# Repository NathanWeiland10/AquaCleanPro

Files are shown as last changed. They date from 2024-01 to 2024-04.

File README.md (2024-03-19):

<p align="center">
    <h1 align="center">Team AquaClean Pro</h1>
</p>

<p align="center">
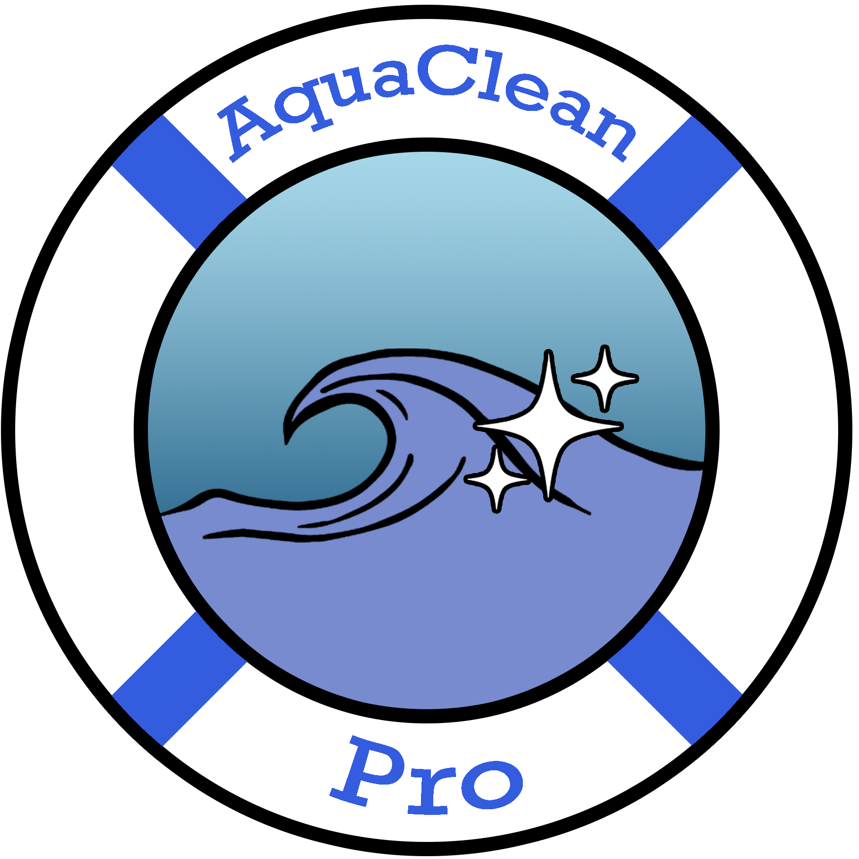
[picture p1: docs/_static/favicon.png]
    
</p>

## Overview
This repository is for Team Projects (CEG 4980 & 4981) from Fall 2023 to Spring 2024, Team #11 - AquaClean Pro. 

### Goal
To create a robot that can autonomously clean the surface of a residential pool and determine its quality. The robot will also have a user interface that will display the metrics of water quality. 

## Custom Domain
Our project uses a custom domain of `aquacleanpro.org` hosted through Squarespace domains. The services provided by under this custom domain can be found below.

1) ### Online Document Viewer
    * The AquaClean Pro Document Viewer (ACP-DV) can be found at [https://docs.aquacleanpro.org/](https://docs.aquacleanpro.org/), which contains information about source code, meeting minutes, and other supporting documentation:
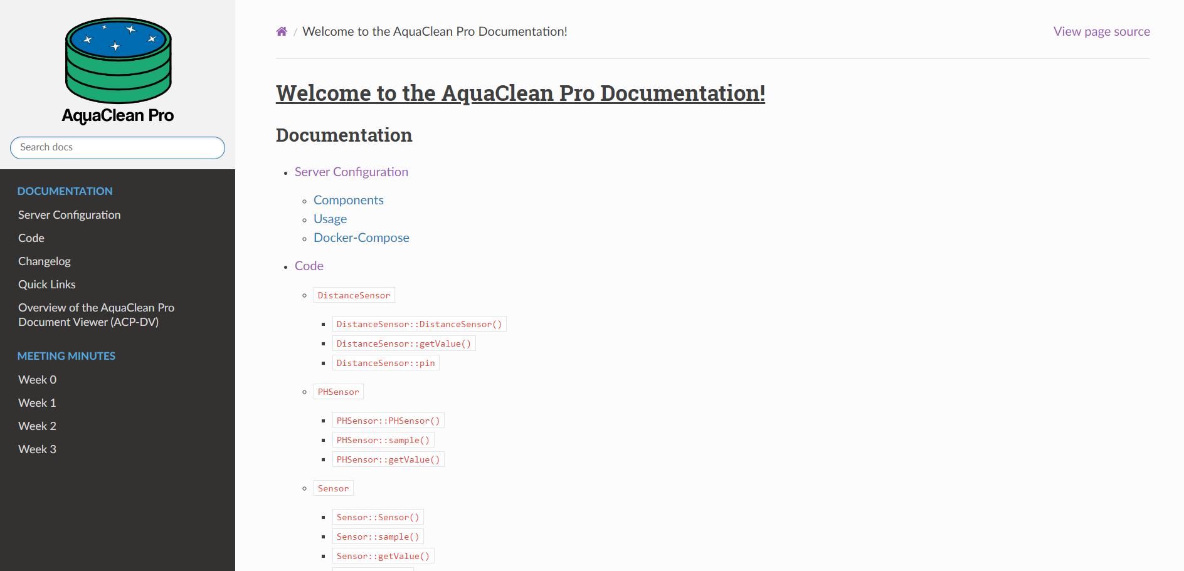
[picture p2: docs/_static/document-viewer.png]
    

2) ### Grafana (Frontend)
    * Our frontend using Grafana can be found at http://www.aquacleanpro.org:8000. Login credentials required.

3) ### pgAdmin (Backend)
    * Our admin portal for Postgres for our project can be found at http://www.aquacleanpro.org:4000/. Login credentials required.

4) ### PostgREST (Backend)
    * Our backend service using PostgREST for our project can be found at http://www.aquacleanpro.org:3000/.

### Model Design

<p align="center">
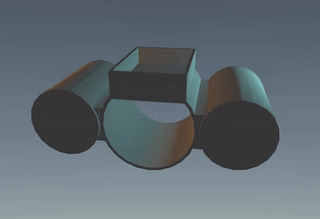
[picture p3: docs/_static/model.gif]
    
</p>

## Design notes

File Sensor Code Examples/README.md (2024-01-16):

## What is This Directory For?
This directory provides some code examples of the sensors that will be used by the Aqua Clean Pro as well as some documentation of where to find more information. A majority of these links have been scraped from links posted in an old Discord group chat.

## Quick References for Components
Below are the store pages for each of our components as well as some links to potentially useful web pages for each:
* ### [ESP32-WROOM-32E - Microprocessor / Microcontroller](https://www.digikey.com/en/products/detail/espressif-systems/ESP32-DEVKITC-32E/12091810)
    * [ESP32 Datasheet](https://www.espressif.com/sites/default/files/documentation/esp32_datasheet_en.pdf)
* ### [DS18B20 - Temperature Sensor](https://www.digikey.com/en/products/detail/adafruit-industries-llc/381/5875807)
* ### [SEN0161 - pH Sensor](https://www.dfrobot.com/product-1025.html)
* ### [Gravity: Analog Signal Isolator ](https://www.digikey.com/en/products/detail/dfrobot/DFR0504/7682221?s=N4IgTCBcDaICIDEBKAGArCgLCAugXyA)
* ### [A02YYUW - Waterproof Ultrasonic Distance Sensor ](https://www.dfrobot.com/product-1935.html)
* ### [Adafruit 3.7V Lithium-Ion Battery 4.4Ah](https://nam04.safelinks.protection.outlook.com/GetUrlReputation)
* ### [1738-1051-ND 2A Dual Motor Controller ](https://www.digikey.com/en/products/detail/dfrobot/DRI0002/6588473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)
* ### [M22E-13 - Propulsion / Steering Motor](https://www.digikey.com/en/products/detail/nmb-technologies-corporation/M22E-13/16677246)

## Other Helpful Links
Below are some links that could possible be useful for reference when coding or working with our electrical components:

## Arduino Specifics
* [Arduino Coding Guide](https://manual.eg.poly.edu/index.php/Arduino_Coding_Guide)
* [Arduino RC Boat Control Code Example](https://forum.arduino.cc/t/movement-of-rudder-on-rc-boat/679347/3)
* [Arduino Battery Level Checking Example](https://forum.arduino.cc/t/battery-level-check-using-arduino/424054/3)
* [Arduino Json](https://arduinojson.org/)

## Coding (C++)
* [C++ Bindings with Python Guide](https://www.blopig.com/blog/2021/03/c-python-bindings-in-5-minutes/)

## Encryption and Wireless Communication
* [802.11 Wi-Fi Standards Guide](https://www.lifewire.com/wireless-standards-802-11a-802-11b-g-n-and-802-11ac-816553)
* [AES (Advanced Encryption Standards) Guide](https://www.techtarget.com/searchsecurity/definition/Advanced-Encryption-Standard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,cybersecurity%20and%20electronic%20data%20protection)
* [AES Encryption Example Repo](https://github.com/kokke/tiny-AES-c)
* [TLS (Transport Layer Security) Guide](https://www.cloudflare.com/learning/ssl/transport-layer-security-tls/)
* [Initialize Wi-Fi Settings in a Production IOT Device](https://electronics.stackexchange.com/questions/495541/how-to-initialize-wifi-settings-in-a-production-iot-device)
* [WPA2 (Wireless Protected Access 2) Guide](https://www.avg.com/en/signal/what-is-wpa2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)

## Waterproofing
* [IP Waterproofing Standards](https://uk.rs-online.com/web/content/discovery/ideas-and-advice/ip-ratings)
* [Waterproof 3D Printing Guide](https://all3dp.com/2/waterproof-3d-print-pla/)

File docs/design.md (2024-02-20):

# Objectives 

**Goal**: To create a robot that can autonomously clean the surface of a residential pool and determine its quality. The robot will also have a user interface that will display the metrics of water quality. 

**Objective 1**: The robot can collect trash and debris on the surface of a body of freshwater. 
- Trash and debris refer to smaller pieces of waste that float on the surface of the water, such as wrappers, bottles, and aluminum cans, and would be unable to collect larger waste.  

**Objective 2**: The robot can take measurements of the water quality. 
- Water quality refers to four main statistics about the body of water the robot resides in: temperature, pH level, total dissolved solids, and turbidity. The robot periodically measures these numbers and transmits them wirelessly to be stored in a database.  

**Objective 3**: A wireless user interface can display metrics measured by the robot. 
- The User Interface could refer to a website that is hosted separately that displays the temperature, the pH level, turbidity, and total dissolved solids of the water; the four metrics the robot collects. 

**Objective 4**: The robot can autonomously move across the surface of the water. 
 - The robot moves across the surface of the water by use of propellors, avoiding collision by utilizing sensors to detect walls. 

# Assumptions 

| No. | Assumption |
|-----|---|
| 1 | The AquaClean Pro will only be operated in residential pools. |
| 2 | The AquaClean Pro will only pick up trash on the surface of the water. |
| 3 | Trash collected by the AquaClean Pro will be no larger than half the size of the attached pool skimmer. |
| 4 | User will provide power to sufficiently charge the AquaClean Pro. |
| 5 | User will provide an internet service for the AquaClean Pro. |
| 6 | The AquaClean Pro functions as a residential pool cleaning robot without an internet service provided by the user. |
| 7 | The AquaClean Pro will not operate in a body of water less than 2 feet deep. |
| 8 | User will not be inside of pool during cleaning. |
| 9 | User will empty the AquaClean Pro’s pool skimmer net when it’s full. |

# Requirements

| Req No. | Obj No. | Requirement |
| --- | --- | --- |
| 1.0 | 1, 4 | AquaClean Pro must collect buoyant solid waste on the surface of a residential pool. |
| 1.1 | 1, 4 | AquaClean Pro must haul at least 0.5 pounds. |
| 2.0 | 2 | AquaClean Pro must measure water quality. |
| 2.0.1 | 2 | The AquaClean Pro must store the water quality data. |
| 2.0.2 | 2, 3 | AquaClean Pro must transmit water quality data over a wireless internet connection at least once every 10 seconds when in operation. |
| 2.0.3 | 3 | AquaClean Pro must display water quality data to a web-accessible user interface. |
| 2.0.4 | 2 | AquaClean Pro shall collect accurate water quality data within an acceptable certainty range. |
| 3.0 | 4 | AquaClean Pro must identify surrounding walls. |
| 3.0.1 | 4 | AquaClean Pro must navigate surrounding walls during operation. |
| 4.0 | 4 | AquaClean Pro must float on the pool's surface. |
| 4.1 | 4 | The AquaClean Pro must reach a speed of at least 20cm/s in a forward direction relative to the device. |
| 4.2 | 4 | The AquaClean Pro must rotate about a fixed position. |
| 4.2.1 | 4 | The AquaClean Pro must have a full 360° rotation range in water along its vertical axis (Yaw). |
| 5.0 | 3 | AquaClean Pro’s battery level must be measured. |
| 5.0.1 | 3 | AquaClean Pro must transmit battery power level over a wireless internet connection at least once every 10 seconds when in operation. |
| 5.0.2 | 3 | AquaClean Pro must display battery power data to a web-accessible user interface. |
| 5.1 | 3, 4 | AquaClean Pro must alert the user once it reaches 20% remaining battery power or lower. |
| 6.0 | 4 | AquaClean Pro is water resistant to a depth of up to 2 feet. |
| 6.1 | 2 | AquaClean Pro’s water quality sensors’ probes must be waterproof. |
| 7.0 | 2, 3 | AquaClean Pro shall connect to a wireless network. |
| 7.0.1 | 2, 3 | The AquaClean Pro shall transmit data to a web-accessible user interface. |
| 7.1 | 2, 3 | The AquaClean Pro shall use end to end encryption for wireless communication. |
| 8.0 | 4 | The AquaClean Pro’s battery shall be charged from an external Micro USB power supply. |

## Definitions
**Buoyant solid waste** – Any objects that are on the surface of the residential pool, including but not limited to leaves, insects, and plastic wrappers. 

**Operation** – The robot’s state while skimming and cleaning the body of water. 

**Water quality data** – Temperature and pH measurements. 

**Acceptable certainty range** – Allowable uncertainty of sensors: 

- pH: ±0.1

- Temperature: ±1°C 

# Constraints 

| No. | Constraint |
| --- | --- |
| 1.0 | Total bill of materials shall not exceed $300 without Faculty Advisor approval. |
| 2.0 | The AquaClean Pro must fit within a box that has dimensions 45cm x 45cm x 60cm. |
| 3.0 | The AquaClean Pro weight must not exceed 20 kg before any trash is collected. |
| 4.0 | The AquaClean Pro’s speed shall not exceed 50cm/s. |
| 5.0 | The battery power shall not exceed 10Ah. |
| 6.0 | The AquaClean Pro wireless communication must adhere to one or more published IEEE standards. |
| 6.0.1 | The AquaClean Pro shall comply with IEEE 802.11 for wireless communication standards. |
| 7.0 | The AquaClean Pro must use end to end encryption for wireless communication. |
| 8.0 | Parts shall be sourced from WSU approved vendors: Digikey, Mouser, Robot Shop, MaxBotix, Midwest Surplus Electronics, or SparkFun. The list of approved vendors is subject to change. Updated lists of approved vendors will be posted in Pilot. |
| 9.0 | AquaClean Pro’s water quality and distance sensors’ probes must be waterproof to IP67 or higher. |

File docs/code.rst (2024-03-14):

====
Code
====

Main
----

.. doxygenfile:: source.ino

Base Sensor Class
-----------------

.. doxygenclass:: Sensor
    :members:

Temperature Sensor
------------------

.. doxygenclass:: TemperatureSensor
    :members:

pH Sensor
---------

.. doxygenclass:: PHSensor
    :members:

Distance Sensor
---------------

.. doxygenclass:: DistanceSensor
    :members:

Motor
-----

.. doxygenclass:: Motor
    :members:

Steering System
---------------

.. doxygenclass:: SteeringSystem
    :members:

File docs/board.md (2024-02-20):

# Development

For ESP-32 development, it is recommended to use the Arduino IDE ([download here](https://www.arduino.cc/en/software)). All required libraries and board interfaces can be installed through the IDE, however, the GitHub URLs are provided just in case.

## Required Libraries

The required libraries can be found by searching in the Arduino IDE's library manager (Tools > Manage Libraries).

- DS18B20 by Mathias Munk Hansen
    - https://github.com/matmunk/DS18B20
- WiFiManager by tzapu
    - https://github.com/tzapu/WiFiManager
- OneWire
    - https://www.pjrc.com/teensy/td_libs_OneWire.html
- HTTPClient by Adrian McEwan
    - https://github.com/amcewen/HttpClient

## Board Configuration

The board interface can be installed through the Arduino IDE's board manager (Tools > Board > Board Manager). The interface that works with our specific board was _DOIT ESP32 DEVKIT V1_ in the "[esp32 by Espressif Systems](https://github.com/espressif/arduino-esp32)" package.

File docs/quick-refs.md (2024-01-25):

# Quick Links

## What is this directory for?
This directory provides some code examples of the sensors that will be used by the Aqua Clean Pro as well as some documentation of where to find more information. A majority of these links have been scraped from links posted in an old Discord group chat.

## Quick References for Components
Below are the store pages for each of our components as well as some links to potentially useful web pages for each:
* ### [ESP32-WROOM-32E - Microprocessor / Microcontroller](https://www.digikey.com/en/products/detail/espressif-systems/ESP32-DEVKITC-32E/12091810)
    * [ESP32 Datasheet](https://www.espressif.com/sites/default/files/documentation/esp32_datasheet_en.pdf)
    * [ESP32 Emulator](https://wokwi.com/esp32)
* ### [DS18B20 - Temperature Sensor](https://www.digikey.com/en/products/detail/adafruit-industries-llc/381/5875807)
    * [Guide for Use With an Arduino #1](https://randomnerdtutorials.com/guide-for-ds18b20-temperature-sensor-with-arduino/)
    * [Guide for Use With an Arduino #2](https://lastminuteengineers.com/ds18b20-arduino-tutorial/)
    * [Guide for Use With an Arduino #3](https://www.instructables.com/How-to-use-DS18B20-Temperature-Sensor-Arduino-Tuto/)
* ### [SEN0161 - pH Sensor](https://www.dfrobot.com/product-1025.html)
    * [Guide for Use With an Arduino #1](https://wiki.dfrobot.com/PH_meter_SKU__SEN0161_)
    * [Guide for Use With an Arduino #2](https://wiki.dfrobot.com/Gravity__Analog_pH_Sensor_Meter_Kit_V2_SKU_SEN0161-V2)
    * [Guide for Use With an Arduino #3 (With GitHub Repo)](https://github.com/DFRobot/DFRobot_PH)
* ### [Gravity: Analog Signal Isolator](https://www.digikey.com/en/products/detail/dfrobot/DFR0504/7682221?s=N4IgTCBcDaICIDEBKAGArCgLCAugXyA)
    * [Component Guide](https://wiki.dfrobot.com/Gravity__Analog_Signal_Isolator_SKU_DFR0504)
* ### [A02YYUW - Waterproof Ultrasonic Distance Sensor](https://www.dfrobot.com/product-1935.html)
    * [Component Guide With Sample Code #1](https://wiki.dfrobot.com/_A02YYUW_Waterproof_Ultrasonic_Sensor_SKU_SEN0311)
    * [Component Guide With Sample Code #2](https://werner.rothschopf.net/microcontroller/202201_a02yyuw_ultrasonic_sensor_en.htm)
* ### [Adafruit 3.7V Lithium-Ion Battery 4.4Ah](https://nam04.safelinks.protection.outlook.com/GetUrlReputation)
* ### [1738-1051-ND 2A Dual Motor Controller](https://www.digikey.com/en/products/detail/dfrobot/DRI0002/6588473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)
    * [Component Guide](https://www.application-datasheet.com/pdf/dfrobot/508812/dri0002.html)
* ### [M22E-13 - Propulsion / Steering Motor](https://www.digikey.com/en/products/detail/nmb-technologies-corporation/M22E-13/16677246)

## Other Helpful Links
Below are some links that could possible be useful for reference when coding or working with our electrical components:

## Arduino Specifics
* [Arduino Coding Guide](https://manual.eg.poly.edu/index.php/Arduino_Coding_Guide)
* [Arduino RC Boat Control Code Example](https://forum.arduino.cc/t/movement-of-rudder-on-rc-boat/679347/3)
* [Arduino Battery Level Checking Example](https://forum.arduino.cc/t/battery-level-check-using-arduino/424054/3)
* [Arduino Json](https://arduinojson.org/)

## Coding (C++)
* [C++ Bindings with Python Guide](https://www.blopig.com/blog/2021/03/c-python-bindings-in-5-minutes/)
* [C++ Coding Guide](https://google.github.io/styleguide/cppguide.html)
* [JSF C++ Coding Standards](https://www.stroustrup.com/JSF-AV-rules.pdf)

## Encryption and Wireless Communication
* [802.11 Wi-Fi Standards Guide](https://www.lifewire.com/wireless-standards-802-11a-802-11b-g-n-and-802-11ac-816553)
* [AES 128 Overview](https://www.techtarget.com/searchsecurity/definition/Advanced-Encryption-Standard)
* [AES (Advanced Encryption Standards) Guide](https://www.techtarget.com/searchsecurity/definition/Advanced-Encryption-Standard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,cybersecurity%20and%20electronic%20data%20protection)
* [AES Encryption Example Repo](https://github.com/kokke/tiny-AES-c)
* [Initialize Wi-Fi Settings in a Production IOT Device](https://electronics.stackexchange.com/questions/495541/how-to-initialize-wifi-settings-in-a-production-iot-device)
* [TLS (Transport Layer Security) Guide](https://www.cloudflare.com/learning/ssl/transport-layer-security-tls/)
* [WPA2 (Wireless Protected Access 2) Guide](https://www.avg.com/en/signal/what-is-wpa2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)

## Waterproofing
* [IEC 60529 (IP Ratings)](https://webstore.iec.ch/preview/info_iec60529%7Bed2.1%7Db.pdf)
* [IP Ratings Overview](https://www.nbcnews.com/select/shopping/what-are-ip-ratings-rcna99835)
* [IP Waterproofing Standards](https://uk.rs-online.com/web/content/discovery/ideas-and-advice/ip-ratings)
* [Waterproof 3D Printing Guide](https://all3dp.com/2/waterproof-3d-print-pla/)

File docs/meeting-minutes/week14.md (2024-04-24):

# Week 14
## Thursday, April 18th, 2024
### Time
- 8:00am - 9:20am
### Attendees/Role
- Nathan
- Ethan T
- Ethan H
- Nermeen
- Thomas
### Decisions Made
- We did bug testing manually on each individual component to ensure they can run at the same time
- Nermeen, Nathan, Ethan T, and Thomas worked on rerouting the motors through the AQP and adding the propellers to them with the new adapters and the silicone sealant
- Ethan H. continues their work on the PostgREST decryption
- Nermeen has taken possession of the pool from Thomas (due to owning a hose)
- Thomas took a video of the motor code testing (before the actual test) for documentation purposes
### Questions or Concerns
- N/A

# Week 14
## Friday, April 19th, 2024
### Time
- 8:00am - 9:20am
### Attendees/Role
- Nathan
- Ethan T
- Ethan H
- Nermeen
- Thomas
### Decisions Made
- Ethan H. finished the decryption, and is now working on implementing encryption
- Thomas & Nathan worked to discover issue in Sensor library (Resolved by Ethan T.).
- Nathan edits videos Thomas took previously of AQP development for the final presentation
- Ethan T. brought in newly printed backplates for the ballasts with holes for rubber inserts (to control the water allowed in)
- Thomas, Nathan, & Nermeen sanded the new back plates to fit the ballasts
- Thomas, Nathan, Nermeen, & Ethan T. applied sealant to the new plates and got them in place
- Ethan T. completed integration of distance, temperature, and ph sensors into one script
### Questions or Concerns
- N/A

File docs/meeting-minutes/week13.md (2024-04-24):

# Week 13
## Thursday, April 11th, 2024
### Time
- 8:00am - 9:20am
### Attendees/Role
- Nathan
- Ethan T
- Ethan H
- Nermeen
- Thomas
### Decisions Made
- Ethan T sent an email to our Advisor (Buck) about presenting on Thursday April 25th at either 8:30am or 9:30am
- Ethan T and Nathan drilled hole in water-proof box to allow pH sensor wire to fit
- Nermeen ordered motor shaft adapters to attach our propellers
    - Issues could arise if we were to directly attach our propellers to the motor shaft since the adhesive could stick to the back of the motor
- Ethan T, Nathan, and Thomas applied more water-proof sealant to the edges of the craft
- Ethan H worked on PostgREST to fix our encrypted buffer table
- Clips were added to the front of the craft to hold our net in place
    - Net
### Questions or Concerns
- N/A

## Friday, April 12th, 2024
### Time
- 8:00am - 1:30pm
### Attendees/Role
- Nathan
- Ethan T
- Ethan H
- Nermeen
- Thomas
### Decisions Made
- Big work day:
    - Some tests for the battery were completed as well as tests for fitting together our components
    - Ethan H continued work on the postgREST side and posting to encryption buffer
    - Nathan, Nermeen, and Ethan T Found bits that we can glue the propellers / motor to and still turn
        - Nermeen will be taking home the motors / propellers to test other bits incase they work better
    - We tested the bot in a utility sink for leaks and waterproofness. It passed the buoyancy test but it failed the leak test.
    - Motor caps were sanded to fit on easier 
- Next steps:
    - Fix issues with integrating our code for our sensors together
    - Complete remaining tests and add results to our complete design document
    - Finish slides for presentation and assign slider numbers
### Questions or Concerns
- N/A

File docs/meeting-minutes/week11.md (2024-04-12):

# Week 11
## Thursday, March 28th, 2024
### Time
- 8:00am - 9:20am
### Attendees/Role
- Nathan
- Ethan T
- Nermeen
- Thomas
### Decisions Made
- Nermeen began work on wiring all of our electrical components together
- Ethan T finished and brought in the full 3D printed model
- Nathan and Thomas began sealing the cracks on the outside of the 3D model pieces to ensure that the design is waterproof
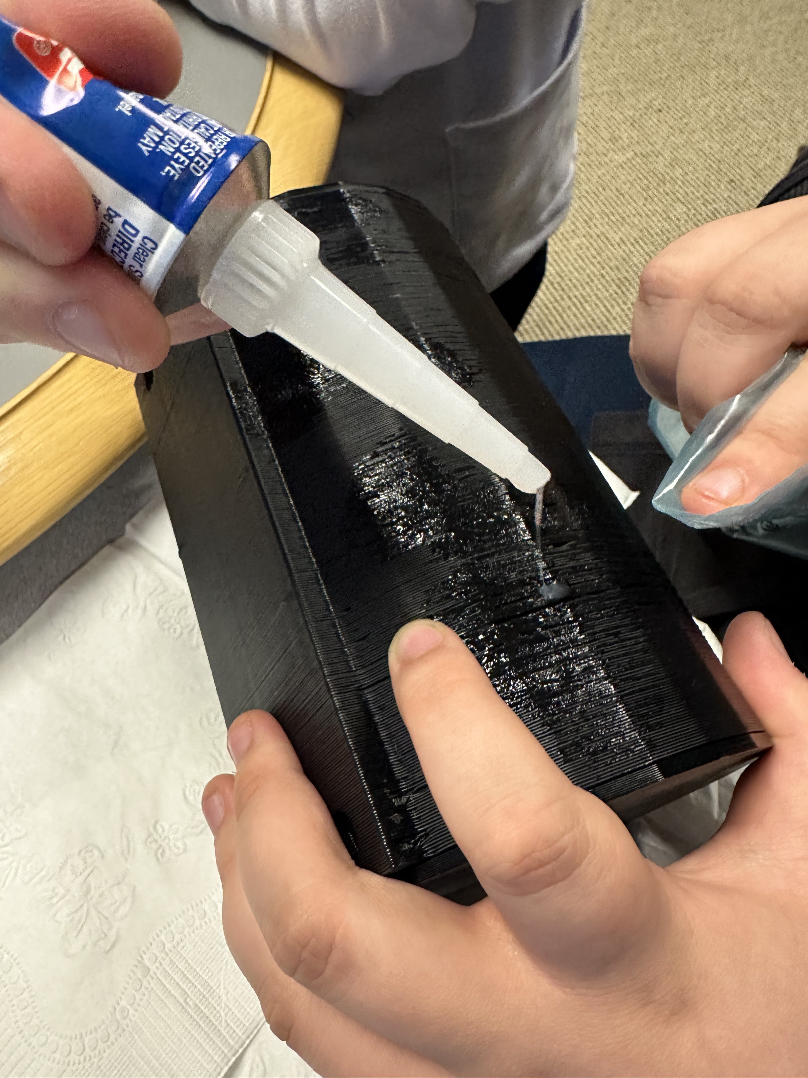
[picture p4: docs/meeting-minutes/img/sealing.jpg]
Sealing
    - 
### Questions or Concerns
- Still waiting for a response from Billy Willis about using the WSU swimming pool for running our tests
    - Possible backup: Buy a small swimming pool from Meijer to test in

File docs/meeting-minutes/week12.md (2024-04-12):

# Week 12
## Tuesday, April 2nd, 2024
### Time
- 8:00am - 9:20am
### Attendees/Role
- Nathan
- Ethan T
- Ethan H
- Nermeen
- Thomas
### Decisions Made
- Ethan T began sanding down the design to ensure a better fit among the different pieces.
- Ethan T, Nermeen, and Nathan also started constructing the whole craft by putting together all the sealed pieces.
- Thomas, Nathan, and Ethan T started sealing up the holes in the craft with the sealant and stuck the various parts of the print together to make the final craft.
- Nermeen and Nathan started assembling the electrical components in the waterproof box to get wires through.
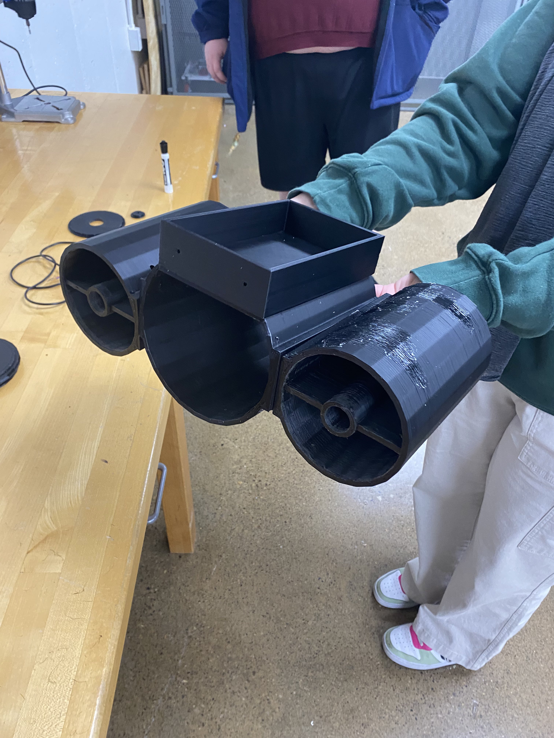
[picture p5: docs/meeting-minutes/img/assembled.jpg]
Together
    - 
- Ethan H is running into issues with the decryption pipeline, currently attempting some fixes to locate where the issue is and fix it before testing next week.
### Questions or Concerns
- From discussing with another group, renting the pool for testing can cost up to $20 an hour
    - To do this, we will also need to fill out a form, which can be found [here](https://www.wright.edu/sites/www.wright.edu/files/page/attachments/facility-request-form_0.pdf)

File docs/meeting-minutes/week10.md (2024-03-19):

# Week 10
## Tuesday, March 19th, 2024
### Time
- 8:00am - 9:20am
### Attendees/Role
- Nathan
- Ethan T
- Ethan H
- Nermeen
- Thomas
### Decisions Made
- We created new propellers due to issues with the propellers we purchased:
    - The propellers we have do not fit well onto our motor bit
    - Issues might arise if we need to glue the propeller shaft to the motor bit, so we would need an extension of the motor shaft
- Our new propeller design addresses both of these issues and we have the ability to adjust the model as needed due to excess filament
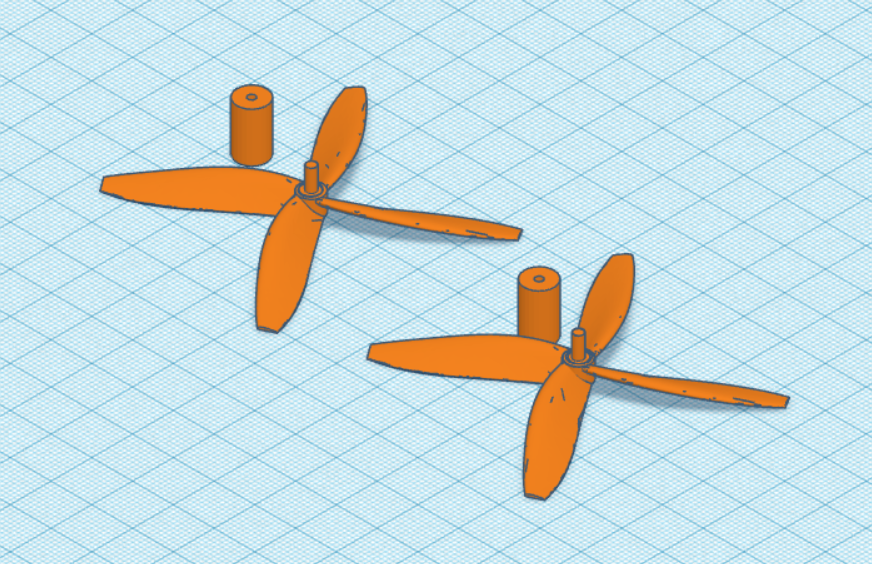
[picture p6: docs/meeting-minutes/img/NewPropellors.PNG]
Propellers
    - 
- Ethan T printed the first segment for the AquaClean Pro
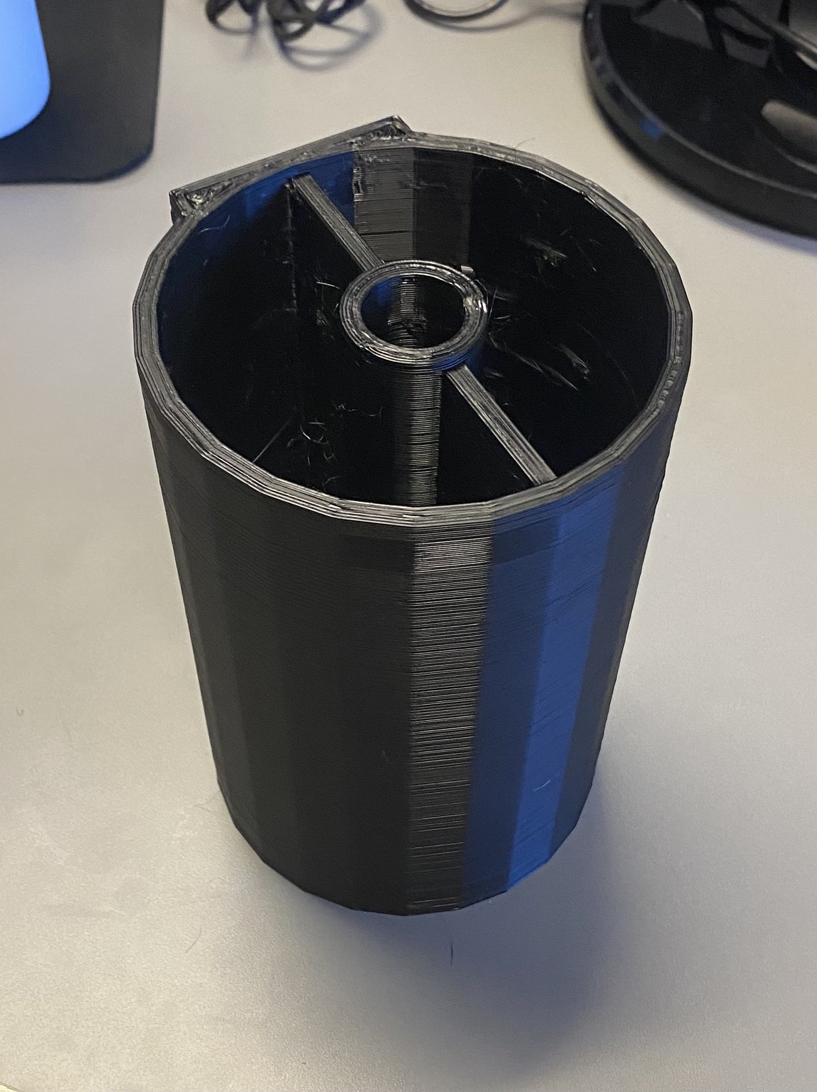
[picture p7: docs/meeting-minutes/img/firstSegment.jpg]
First_Segment
    - 
- Ethan T calibrated the pH sensor to get the correct values for the pH offset (526.035) and curve (143.133)
### Questions or Concerns
- N/A

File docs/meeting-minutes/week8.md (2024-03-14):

# Week 8
## Thursday, March 7th, 2024
### Time
- 8:30am - 9:20am
### Attendees/Role
- Nathan
- Ethan T
- Ethan H
- Nermeen
- Thomas
### Decisions Made
- Ethan T and Nermeen worked on distance sensor and motor code and tested on an ESP-32
- Nathan, Ethan H, and Thomas worked on testing encryption code on an ESP-32
    - The code worked, however, the encrypted data will need to be converted into JSON format and a new table will need to be created in PostgREST
- Nathan and Ethan T went to Russ basement to test motor and motor drivers on ESP-32 with voltages of 3.7 and 6.5. Both cases were successful
### Questions or Concerns
- Our battery is 3.7V, however, a design sheet specifies that we need 6.5V for our motor driver.
    - From testing, we found that the motor driver still works with only 3.7V, but a new battery can be purchased if necessary
- Our motors are not waterproof
    - We have the budget to buy new motors, or we can use our waterproof sealant to waterproof the motors

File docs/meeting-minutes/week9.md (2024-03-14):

# Week 9
## Thursday, March 14th, 2024
### Time
- 8:30am - 9:20am
### Attendees/Role
- Nathan
- Ethan T
- Ethan H
- Nermeen
- Thomas
### Decisions Made
- We tested our pH sensor and was able to correctly read in values. A calibration testing kit has purchased by Ethan T so that we can ensure the values read in are correct
- We decided to update the 3D model for the AquaClean Pro. Tinkercad was used for the software since it was simpler to use and allowed us all to view and make changes to the model at the same time. The new model also addresses some of the issues we found with the previous model, such as the buoyancy and balance of the model, pathing of the wires from the water-proof box to the motors, and potential issues when printing the model (such as needing supports)
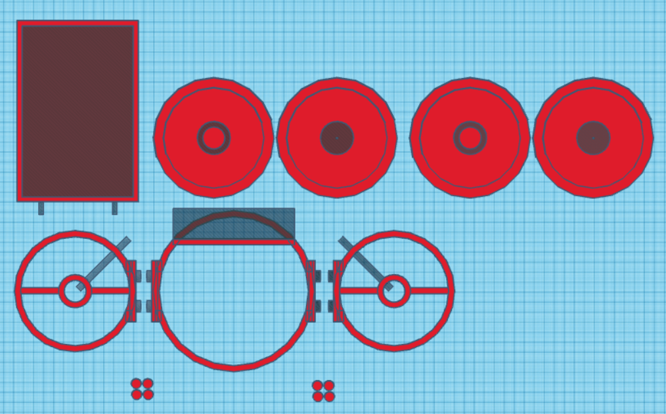
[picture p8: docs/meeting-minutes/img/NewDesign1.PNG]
    - 
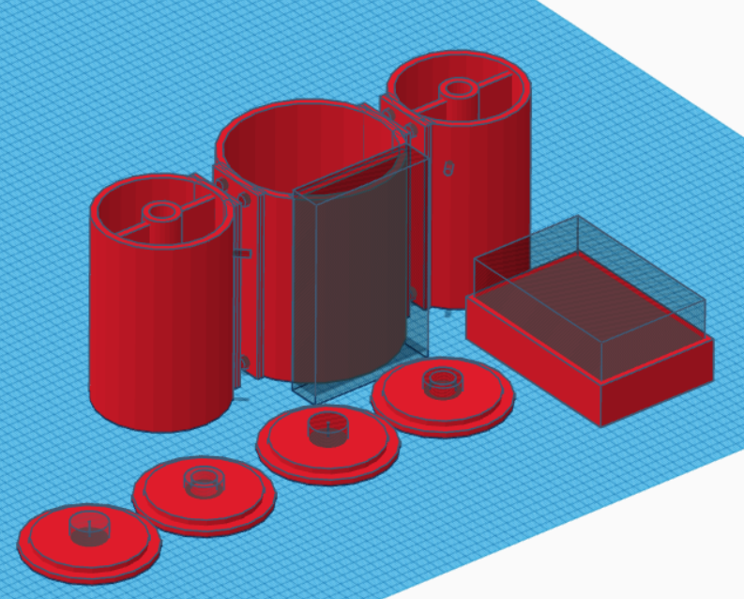
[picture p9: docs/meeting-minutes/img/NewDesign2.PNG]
    - 
- We are hoping to have the 3D model completed and printed by next week so that we can begin integrating our components
### Questions or Concerns
- N/A

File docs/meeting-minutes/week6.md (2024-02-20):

# Week 6
## Tuesday, February 20, 2024
### Time
- 9:00am - 9:20am
### Attendees/Role
- Nathan
- Ethan T
- Ethan H
- Nermeen
- Thomas
### Decisions Made
- Ethan H worked on demoes for encryptions on Arduino and PostgREST in C
- Ethan T added to the online document viewer a development tab for configuring code in the Arduino IDE
- A majority of team member installed the Arduino IDE and tested to make sure code could be compiled
    - The WiFi setup code written by Ethan T was tested
- Over spring break, we won't assign any new action items, however, team members can pick up work if they would like to
### Questions or Concerns
- N/A

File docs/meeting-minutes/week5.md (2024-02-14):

# Week 5
## Tuesday, February 13, 2024
### Time
- 8:30am - 9:20am
### Attendees/Role
- Nathan
- Ethan T
- Ethan H
- Nermeen
- Thomas
### Decisions Made
- Movement controls using the distance sensor; two possible options
    - 1: Start the bot in a corner and have it move straight until it reaches the next corner. Rotate the bot 90 degrees, move forward a small amount, rotate another 90 degrees, then move forward until it reaches a wall. Continue this until the bot reaches a corner. This could potentially still work if the bot is not placed directly in the corner
        - 
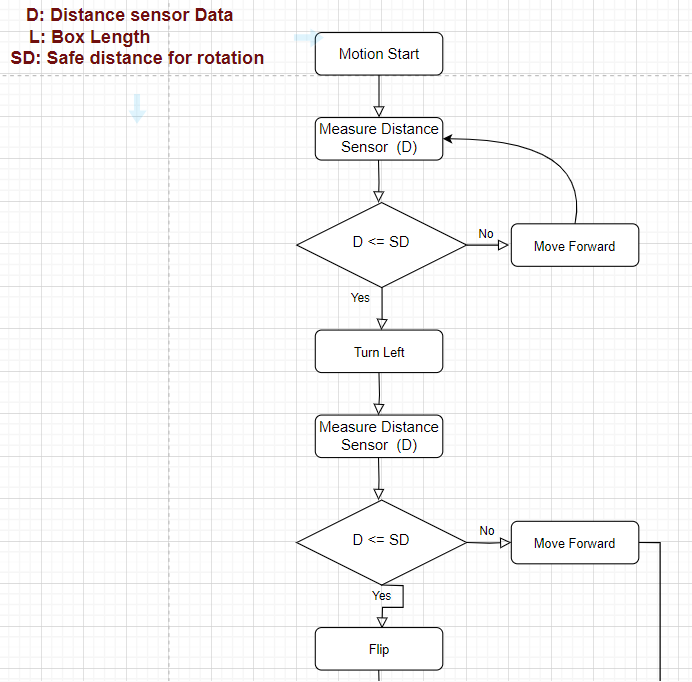
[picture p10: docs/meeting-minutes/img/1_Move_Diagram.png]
        - 
        - 
    - 2: Have the bot move forward from anywhere starting in the pool. Once the bot reaches a wall, have the bot rotate until it no longer is within a certain range of the wall, rotate a certain number of additional degrees (value can be tweaked later), and move forward. Continue this process.
        - 
    - Both designs
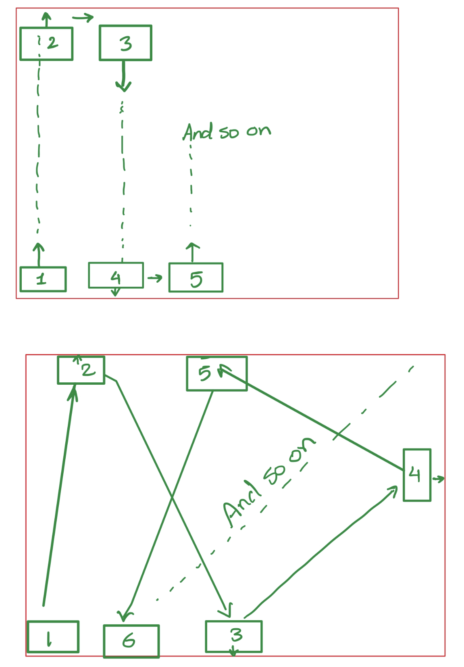
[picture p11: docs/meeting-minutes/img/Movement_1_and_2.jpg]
    - 
 - <b>Action Items:</b>
    - Nermeen: Distance sensor coding (using personal ESP)
    - Ethan T: pH sensor coding (using personal ESP)
    - Ethan H: Focusing on PostgREST
    - Nathan: Motor coding (using Tinkercad with an Arduino)
    - Thomas: Temperature sensor coding (using Wokwi emulator - DS18B20)
### Questions or Concerns
- Drilling holes into the waterproof box to allow the wiring to go through
    - We will manually drill holes into the box rather than using the sealing nuts so it will fit the design we have created. The only external wiring would be for the two motors and the distance sensor. We can waterproof by using the sealant we have.
- The motors we got did not come with wires, but we have ones we can use.

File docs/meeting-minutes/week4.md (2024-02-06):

# Week 4
## Tuesday, February 6, 2024
### Time
- 8:30am - 9:20am
### Attendees/Role
- Nathan
- Ethan T
- Ethan H
- Nermeen
- Thomas
### Decisions Made
- Update the 3D model:
    - Removing a section of the back wall and replacing it with L-shaped channels for wiring (removing the blue square area). This will allow for extra room for netting and to reduce drag in the water.
    - Adding counterweight for motors by filling in the front portions of the ballasts of where our motors will be (the red circles).
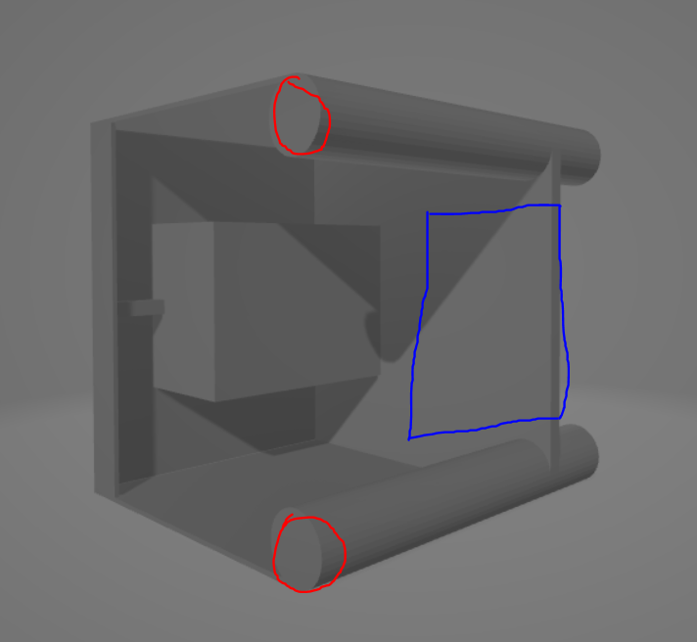
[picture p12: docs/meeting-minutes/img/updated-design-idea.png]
    
- Possibility of adding cosmetics or decorations after printing as time allows.
- Meeting at Joshi 367 on Tuesdays, and meeting on Thursdays at Joshi 367 if needed. Tuesday was chosen over Thursday because it is earlier in the week, providing us with more time to work.
### Questions or Concerns
- Talk to Billy about finding where our parts are. We checked the basement of Russ and they were not there.

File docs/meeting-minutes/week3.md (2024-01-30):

# Week 3
## Tuesday, January 30, 2024
### Time
- 8:00am - 9:20am
### Attendees/Role
- Nathan
- Ethan T
- Ethan H
- Nermeen
- Thomas
### Decisions Made
- Propellors will be difficult to 3D print. Instead, we will order them from Amazon. The following link was chosen due to their shaft width (3mm) and diameter (32mm) to fit the existing enclosure design. Nermeen has emailed Billy to add it to our order. (https://www.amazon.com/dp/B07RHK1TFS/ref=sspa_dk_detail_9)
- The pH sensor we ordered was on backorder until March 8th. We've found the following alternative available on Amazon which will hopefully arrive before March 8th and emailed Lynn Rhea asking to replace the item. (https://www.amazon.com/Accuracy-Connect-Terminal-Electrode-Detection/dp/B08GYF269Y)
- **Action Items:**
    - Ethan H will figure out the decryption between PostgreSQL/PostgREST and Grafana. Executing the TinyAES decryption function inside PostgreSQL may be a solution.
    - Nathan will update the documentation on how to update the documentation.
    - Thomas will try to emulate a pH sensor with WOKWI.
    - Ethan T will start trying to print the enclosure.
### Questions or Concerns
- Buck let us know that we're allowed to meet only once a week and it doesn't have to be during our scheduled class time or in SSC. Do we want to start meeting one day a week? Do we want to meet in Russ? If we want to meet during a time outside of our scheduled class, Buck has to be available.

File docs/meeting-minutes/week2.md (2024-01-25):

# Week 2
## Thursday, January 25th, 2024
### Time
- 8:30am - 9:00pm
### Attendees/Role
- Nathan
- Ethan T
- Ethan H
- Nermeen
- Thomas
### Decisions Made
- Using pre-made propellers instead of printing them
    - Adjust the width of the propeller ports from 40mm to 45mm
    - Nathan will send an email to Buck and Billy to include the pre-made propeller in our budget / list of materials
- Since our parts still have not arrived, we can use some of our own equipment for testing, such as testing with an ESP-32, or use online emulators.
- Ensure that Grafana is connected with the backend for sending data
- **Action Items:**
    - Ethan H will work on the Grafana display
    - Ethan T will work on connectivity of the ESP-32
    - Nathan will work on the issues with GitHub pages and finish the documentation for the docs viewer
    - Nermeen will focus on the 3D printing / motor housing and setup Tinkercad accounts
    - Thomas will focus on using Tinkercad / Wowki for writing code for the ESP-32
### Questions or Concerns
- Concern: Check in to see the status of our parts - especially for 3D printing
- Issue with GitHub pages resetting our custom domain of "docs.aquacleanpro.org" - we may need to configure the settings in Squarespace

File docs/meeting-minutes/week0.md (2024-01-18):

# Week 0
## Tuesday, January 9th, 2024
### Time
- 9:00am - 9:20am
### Attendees/Role
- Nathan
- Ethan T
- Ethan H
- Nermeen
### Decisions Made
- Hollowing the 3D printed design; walls will be less than 5cm
### Questions or Concerns
- How / where to host our server?
- AquaClean Pro Design:
    - How to design in a way that we can wire the motors?

## Thursday, January 11th, 2024
### Time
- 8:45am - 9:20am
### Attendees/Role
- Nathan
- Ethan T
- Ethan H
- Nermeen
- Thomas
### Decisions Made
- Thomas will create folder in the Sharepoint and template for final report as well as create template for presentation
- Ethan H will focus on setting up PostgreSQL
- Ethan T will focus on setting up the server to host the AquaCleanPro and created a Discord server for communication
- Nermmen will submit the bill of materials again and focus on the 3D model of the AquaCleanPro
    - Issue: What size should the hatch be to hold the water proof box?
        - Possible solution: Design the hatch slightly larger than the box (+10mm for each dimension) and use clear epoxy to fill in the space
- Nathan will create a folder in this GitHub repo with samples and documentation of sensor code for use with the Arduino
### Questions or Concerns
- Determine the status of our bill of materials
- After a few weeks, discuss with our advisor the possibility of meeting at a separatime time and location

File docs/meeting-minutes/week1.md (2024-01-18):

# Week 1
## Thursday, January 18th, 2024
### Time
- 9:00am - 9:20am
### Attendees/Role
- Nathan
- Ethan T
- Ethan H
- Nermeen
### Decisions Made
- Switching to a more catamaran-esque design for the bot to help with buoyancy/balance.
### Questions or Concerns
- How large should the device be?
    - Must fit on the print bed
    - Must be less than 3kg total
    - Must be large enough to fit our components

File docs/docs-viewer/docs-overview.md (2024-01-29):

# Overview of the AquaClean Pro Document Viewer (ACP-DV)
* The ACP-DV can be found at [https://nathanweiland10.github.io/AquaCleanPro/](https://nathanweiland10.github.io/AquaCleanPro/) or under the custom domain [https://docs.aquacleanpro.org/](https://docs.aquacleanpro.org/).
* The ACP-DV contains source code for the AquaClean Pro, meeting minutes, and other useful links and resources regarding the development and use of the AquaClean Pro.

## Adding Files to the ACP-DV
* To add files to the ACP-DV, follow these steps:
    1) Create a new GitHub branch from the repo: [https://github.com/NathanWeiland10/AquaCleanPro](https://github.com/NathanWeiland10/AquaCleanPro) and create a markdown file. Typically these files should be placed in the `docs` directory.
    2) Under the `docs` directory, locate the `index.rst` file. The file should look like the following:
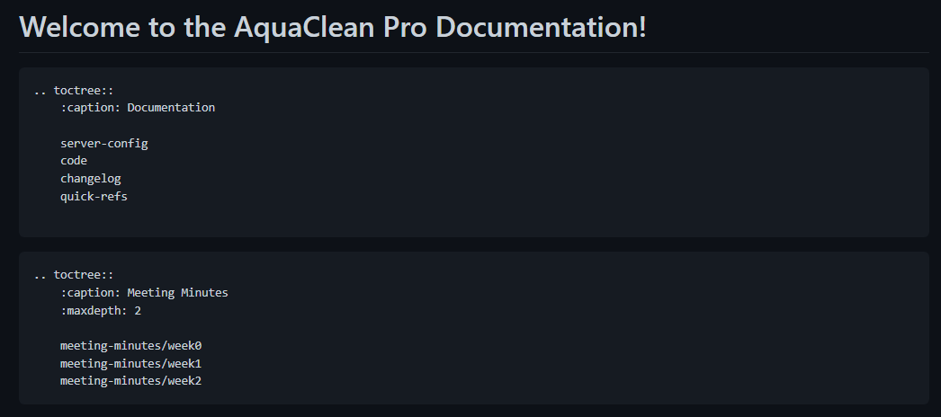
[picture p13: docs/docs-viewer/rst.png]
index.rst File
        * 
    3) Either add to an existing `.. toctree::` or create a new one. Creating a new `.. toctree::` with a specified caption will create a header in the ACP-DV, as shown in the following for "Documentation":
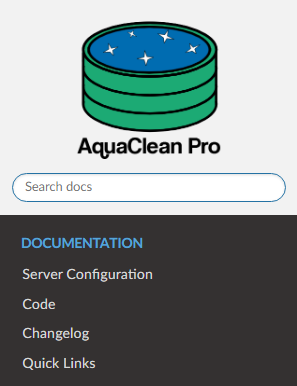
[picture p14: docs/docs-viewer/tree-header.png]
Tree Header
        * 
    4) Add the relative path of the markdown file under the `.. toctree::`.
    5) Upload your branch / push your changes to the [GitHub repo](https://github.com/NathanWeiland10/AquaCleanPro). An automated job should be ran which will allow you to view the ACP-DV before it goes live at https://docs.aquacleanpro.org/. This can be found by clicking on the `Actions` tab, then the changes you pushed. Near the bottom you will find the local version of the ACP-DV. Extract the file and open `index.html`:
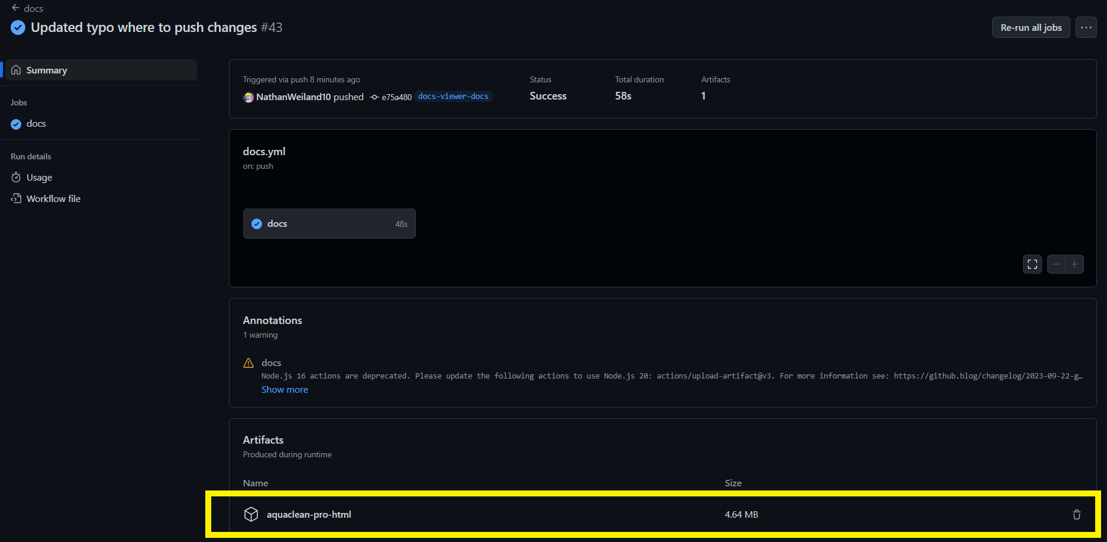
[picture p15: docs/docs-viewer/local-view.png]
Local View
        * 
    6) Push your changes to the `main` branch after you have viewed the local version of the ACP-DV and are satisfied with the changes. An automated script will be ran to add your changes to the live ACP-DV, which can be found at https://docs.aquacleanpro.org/.

## Notes About Markdown Files in the ACP-DV
* Header levels matter in your markdown files regarding the ACP-DV. A header level of one (i.e., a single hashtag `#`) will act as a header for the name of the file. For example, in the below example, the level one header of the file will be displayed in the viewer (Ex: "Server Configuration"), **not the name of the file itself**:
    * Tree Header

## Current Issues with the ACP-DV
* When changes are pushed to the `gh-pages` branch, the custom domain of `docs.aquacleanpro.org` is reset and manually needs to be updated in the [GitHub repo](https://github.com/NathanWeiland10/AquaCleanPro) under Setting -> Pages -> Custom domain:
    * Custom Domain

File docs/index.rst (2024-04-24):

###########################################
Welcome to the AquaClean Pro Documentation!
###########################################

.. toctree::
    :caption: Design

    design
    
.. toctree::
    :caption: Documentation

    server-config
    board
    code 
    changelog
    quick-refs
    docs-viewer/docs-overview

.. toctree::
    :caption: Meeting Minutes
    :maxdepth: 2

    meeting-minutes/week0
    meeting-minutes/week1
    meeting-minutes/week2
    meeting-minutes/week3
    meeting-minutes/week4
    meeting-minutes/week5
    meeting-minutes/week6
    meeting-minutes/week8
    meeting-minutes/week9
    meeting-minutes/week10
    meeting-minutes/week11
    meeting-minutes/week12
    meeting-minutes/week13
    meeting-minutes/week14

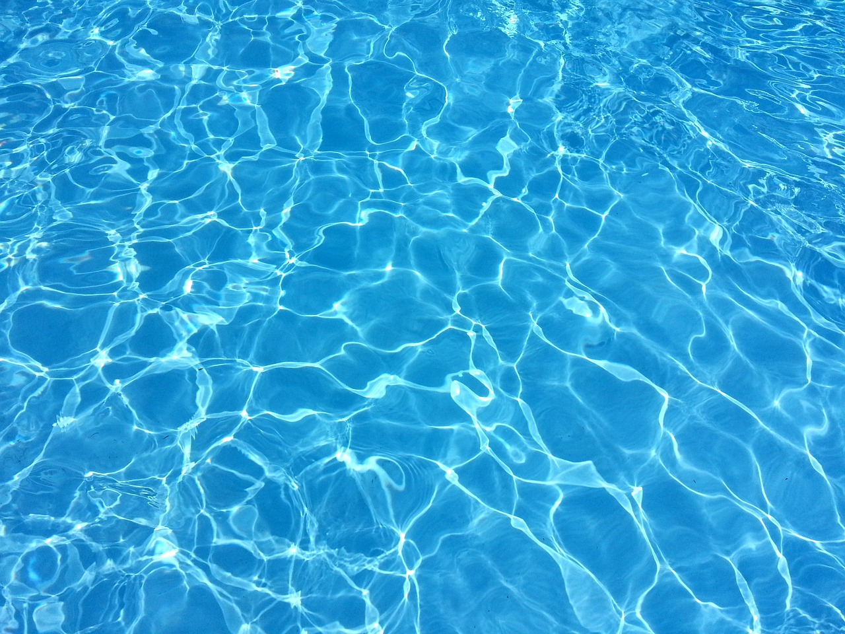
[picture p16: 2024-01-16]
docs/_static/pool.jpg

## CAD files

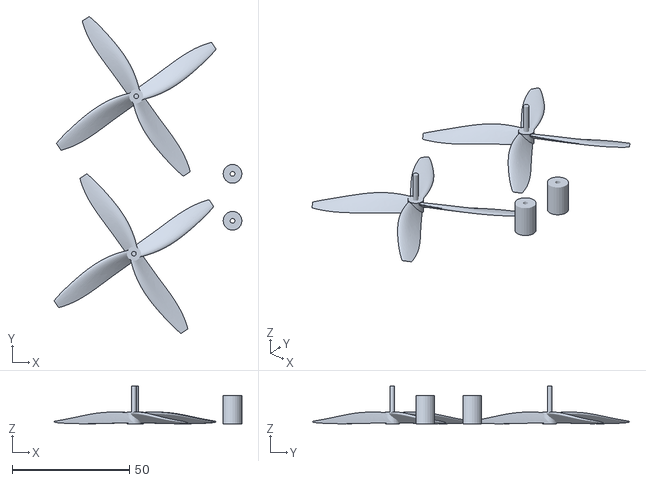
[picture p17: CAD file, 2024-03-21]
models/propellors.stl
80.0 x 135.0 x 16.0

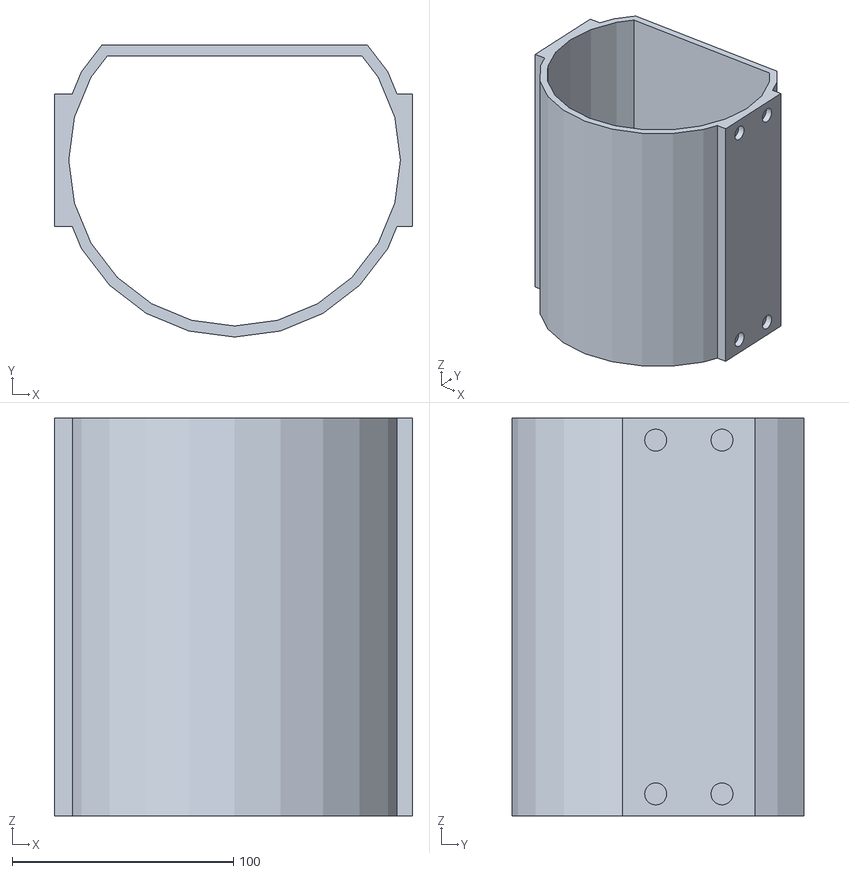
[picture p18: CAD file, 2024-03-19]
models/middle-collector.stl
162.0 x 132.1 x 180.0

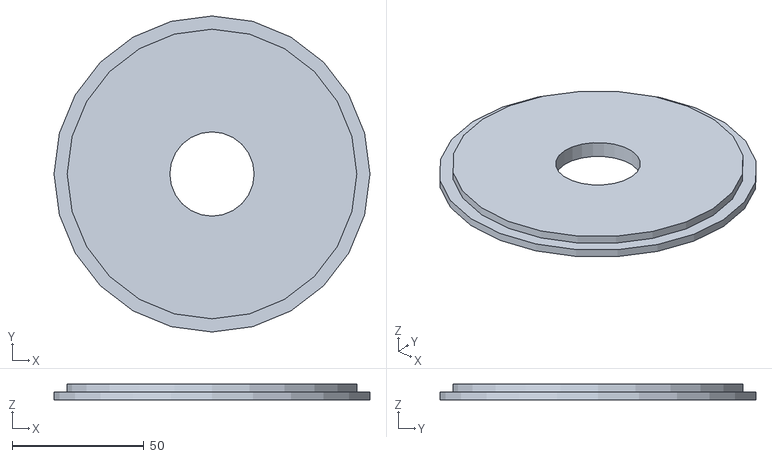
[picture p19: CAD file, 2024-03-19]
models/big-cap-with-hole.stl
120.0 x 120.0 x 6.00

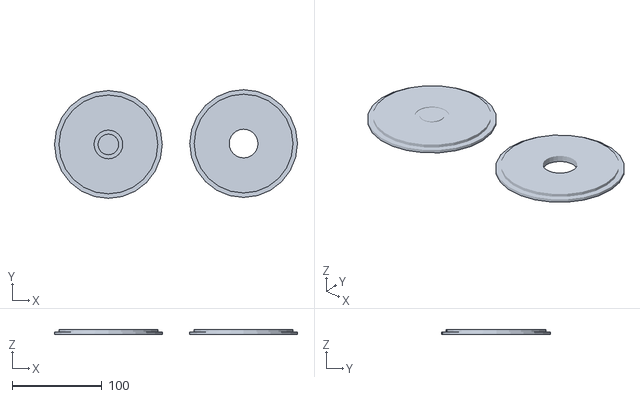
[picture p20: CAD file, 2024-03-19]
models/big-caps.stl
270.5 x 121.0 x 6.00

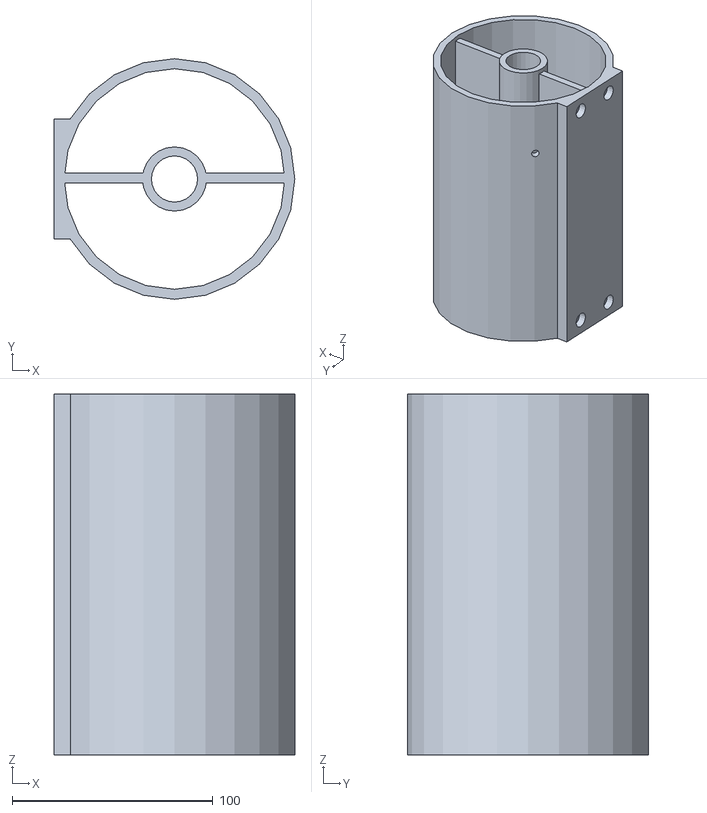
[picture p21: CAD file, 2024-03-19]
models/right-ballast.stl
120.0 x 120.0 x 180.0

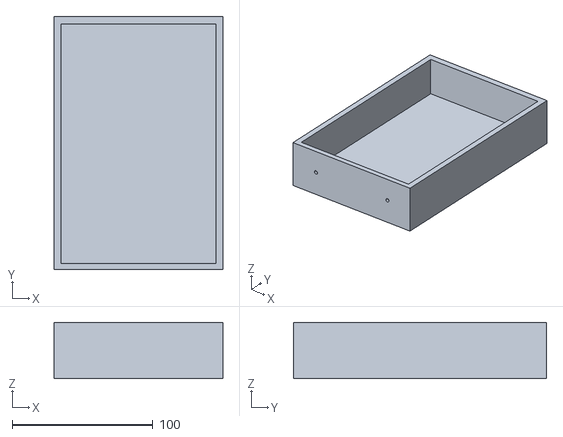
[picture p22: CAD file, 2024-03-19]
models/top-box.stl
120.0 x 180.0 x 40.0

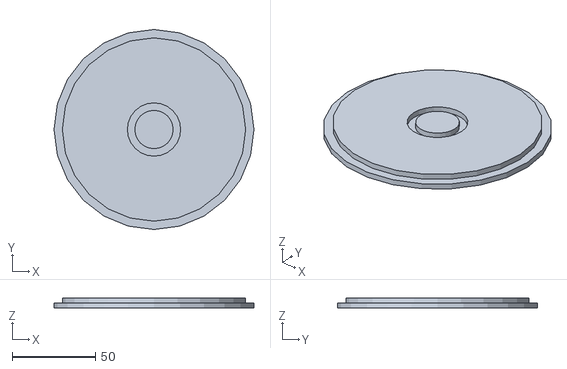
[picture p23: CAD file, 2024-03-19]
models/big-cap-no-hole.stl
120.0 x 120.0 x 6.00

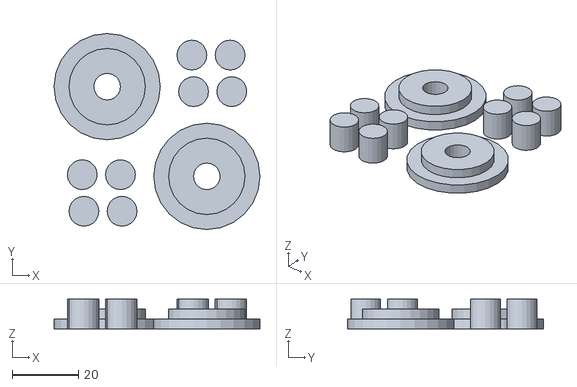
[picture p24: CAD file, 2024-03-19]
models/caps-and-pegs.stl
62.0 x 59.0 x 9.00

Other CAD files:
models/left-ballast.stl

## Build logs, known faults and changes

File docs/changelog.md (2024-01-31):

# Changelog

## Week 3
- Added WiFi portal and HTTP POST functionality. Currently uploads dummy data.

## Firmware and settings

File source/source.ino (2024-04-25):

#include "Arduino.h"
#include <WiFiManager.h>
#include <HTTPClient.h>
#include "sensors.hpp"
#include "motor.hpp"
#include "steering-system.hpp"
#include "battery.hpp"
#include <SoftwareSerial.h>
#include <OneWire.h>
#include <DallasTemperature.h>

#define TEMP_PIN 27
#define PH_PIN 36
#define DIST_RX_PIN 14
#define DIST_TX_PIN 13
#define LEFT_MOTOR_E_PIN 17
#define LEFT_MOTOR_M_PIN 16
#define RIGHT_MOTOR_E_PIN 32
#define RIGHT_MOTOR_M_PIN 33
#define POSTGREST_URL "http://aquacleanpro.org:3000/water_data"
#define TURN_WITHIN_DISTANCE 20
#define BATTERY_PIN 35

WiFiManager wifiManager;            ///< WiFi manager instance used to create WiFi portal
WiFiManagerParameter runtimeParam;  ///< Device runtime parameter configured in WiFi portal

int totalRuntime = -1;            ///< Total time in seconds that the device will run before shutting down. Initialized at -1 until configured from WiFi portal.
int runtime = 0;                  ///< Time in seconds that the device has been active.
hw_timer_t *runtimeTimer = NULL;  ///< Hardware timer used to increment runtime every second.

OneWire oneWireTemp(TEMP_PIN);
DallasTemperature tempSensor(&oneWireTemp);

Battery battery(BATTERY_PIN, 3.4);
PHSensor phSensor(PH_PIN);
Motor leftMotor(LEFT_MOTOR_E_PIN, LEFT_MOTOR_M_PIN);
Motor rightMotor(RIGHT_MOTOR_E_PIN, RIGHT_MOTOR_M_PIN);
SteeringSystem steeringSystem(leftMotor, rightMotor);

SoftwareSerial mySerial(14, 13);  // RX, TX
unsigned char data[4] = {};
float distance;

/// @brief Interrupt service routine that increments runtime every second.
void IRAM_ATTR onTimer() {
  runtime++;
  steeringSystem.update();
}

/// @brief Runs once on start-up. Initializes WiFi, ISR, and Serial connection
void setup() {
  Serial.begin(115200);
  tempSensor.begin();
  initTimer();
  initWifiPortal();
  pinMode(PH_PIN, INPUT);
  steeringSystem.go();
}

/// @brief Main update loop
void loop() {
  wifiManager.process();

  if (runtime >= totalRuntime) {
    for (int i = 0; i < 8; i++) {
      phSensor.sample();
    }

    uploadMeasurements();

    steer();
  }
  else {
    steeringSystem.stop();
  }
}

/// @brief Initializes the hardware timer used to calculate device runtime.
void initTimer() {
  runtimeTimer = timerBegin(0, 80, true);
  timerAttachInterrupt(runtimeTimer, &onTimer, true);
  timerAlarmWrite(runtimeTimer, 1000000, true);
  timerAlarmEnable(runtimeTimer);
}

/// @brief Initializes the WiFi portal to obtain network credentials.
void initWifiPortal() {
  //wifiManager.resetSettings(); // Remove in real build
  wifiManager.setConfigPortalBlocking(true);
  const char *runtimeHtml = "<br/><label for='runtime'>Runtime</label><br><input type='radio' name='runtime' value='15' checked> 15 minutes <br><input type='radio' name='runtime' value='30'> 30 minutes <br><input type='radio' name='runtime' value='60'> 1 hour";

  new (&runtimeParam) WiFiManagerParameter(runtimeHtml);
  wifiManager.addParameter(&runtimeParam);
  wifiManager.setSaveParamsCallback(saveParamCallback);

  std::vector<const char *> menu = { "wifi", "param", "sep", "restart", "exit" };
  wifiManager.setMenu(menu);
  wifiManager.setClass("invert");  // Dark mode
  wifiManager.setConfigPortalTimeout(600);
  wifiManager.autoConnect("AquaClean Pro Setup");
}

/// @brief Saves runtime setting from WiFi portal to device
void saveParamCallback() {
  if (wifiManager.server->hasArg("runtime")) {
    totalRuntime = wifiManager.server->arg("runtime").toInt();
  }
}

/// @brief Uploads the temperature and pH data to PostgREST (currently uploads fake data)
/// @return The HTTP response code
int httpUpload(float temp, float ph, float charge) {
  if (WiFi.status() == WL_CONNECTED) {
    HTTPClient http;
    http.begin(POSTGREST_URL);
    int httpResponseCode = http.POST("{ \"temp\": " + String(temp) + ", \"ph\": " + String(ph) + ", \"battery\": " + String(charge) + " }");
    http.end();
    return httpResponseCode;
  } else return 0;
}

/// @brief Gets and uploads temperature and pH measurements to PostgREST
/// @return Returns the HTTP response code
int uploadMeasurements() {
  float ph = phSensor.getValue();
  tempSensor.requestTemperatures();
  float temp = tempSensor.getTempFByIndex(0);
  float charge = battery.getCharge();

  Serial.println("Temp: " + String(temp) + " F");
  Serial.println("pH: " + String(phSensor.getValue()));
  Serial.println("Battery: " + String(charge * 100) + "%");

  return httpUpload(temp, ph, charge);
}

/// @brief Gets the distance in cm from the ultrasonic sensor
/// @return Returns the distance in cm
float getDistance() {
  float distance;
  unsigned char checksum;
  char header;
  int data_buffer[4];

  Serial2.begin(9600, SERIAL_8N1, DIST_RX_PIN, DIST_TX_PIN);

  // Wait until 4 packets are available
  while (Serial2.available() < 3) {
    delay(100);
  }

  // Read until header is found
  do {
    data_buffer[0] = Serial2.read();
  } while (data_buffer[0] != 0xff);

  // Wait until 3 more packets are found
  while (Serial2.available() < 2) {
    delay(10);
  }

  for (int j = 1; j < 4; j++) {
    data_buffer[j] = Serial2.read();
  }

  // Get distance if checksum is valid
  checksum = data_buffer[0] + data_buffer[1] + data_buffer[2];
  if (data_buffer[3] == checksum) {
    distance = (float)((data_buffer[1] << 8) + data_buffer[2]) / 10;
  } else {
    distance = -1;
  }

  Serial2.end();
  return distance;
}

/// @brief Detects walls and steers the craft around them
void steer() {
  float distance = getDistance();
  Serial.println("Distance: " + String(distance) + " cm");
  if (distance < TURN_WITHIN_DISTANCE) {
    steeringSystem.turnRight();
  }
}

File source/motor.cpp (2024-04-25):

#include "motor.hpp"
#include "Arduino.h"

/// @brief Default constructor for a motor controlled by the L298N
Motor::Motor(){

}

/// @brief Default constructor for a motor controlled by the L298N
/// @param pinNumE Pin E of the motor
/// @param pinNumM Pin M of the motor
Motor::Motor(int pinNumE, int pinNumM){
  pinE = pinNumE;
  pinM = pinNumM;

  pinMode(pinE, OUTPUT);
  pinMode(pinM, OUTPUT);
}

/// @brief Stops the motor
void Motor::stop(){
  digitalWrite(pinE, LOW);
  digitalWrite(pinM, LOW);
}

/// @brief Turns the motor forward at full speed
void Motor::turnForward(){
  digitalWrite(pinE, HIGH);
  digitalWrite(pinM, HIGH);
}

/// @brief Turns the motor backwards at full speed
void Motor::turnBackward(){
  digitalWrite(pinE, HIGH);
  digitalWrite(pinM, LOW);
}

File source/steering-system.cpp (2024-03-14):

#include "steering-system.hpp"
#include "motor.hpp"

/// @brief Default constructor of the steering system
/// @param left Reference to the left motor
/// @param motor Reference to the right motor
SteeringSystem::SteeringSystem(Motor left, Motor right){
  leftMotor = left;
  rightMotor = right;
  state = STOPPED;
}

/// @brief Stops the movement of the craft
void SteeringSystem::stop(){
  state = STOPPED;
  leftMotor.stop();
  rightMotor.stop();
}

/// @brief Makes the craft go forward
void SteeringSystem::go(){
  state = FORWARD;
  leftMotor.turnForward();
  rightMotor.turnForward();
}

/// @brief Turns the craft right
void SteeringSystem::turnRight(){
  state = TURNING_RIGHT;
  turnTimer = TURN_TIME;
  leftMotor.turnForward();
  rightMotor.turnBackward();
}

/// @brief Turns the craft left
void SteeringSystem::turnLeft(){
  state = TURNING_LEFT;
  turnTimer = TURN_TIME;
  leftMotor.turnBackward();
  rightMotor.turnForward();
}

/// @brief Updates the steering timer
void SteeringSystem::update(){
  // Decrement turnTimer if turning
  if (state == TURNING_LEFT || state == TURNING_RIGHT)
  {
    turnTimer -= 1;

    // Reset to forward motion when turnTimer is 0
    if (turnTimer == 0){
      turnTimer = TURN_TIME;
      go();
    }
  }
}

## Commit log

2024-01-12 switched to secret container reg token
2024-01-25 added wifi portal code - currently untested
2024-01-30 Print IV and buffer info
2024-02-06 Print key and IV to txt
2024-02-13 Print encrypted buffer to file
2024-02-13 Print buffer, fix key read
2024-02-20 added board config docs
2024-03-05 added distance sensor code (untested)
2024-03-11 Added steering system code
2024-03-15 Distance sensor test code
2024-03-19 added models and battery charge code
    [big-cap-no-hole.stl, big-cap-with-hole.stl, big-caps.stl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]
2024-03-21 Added propellors.stl
    [propellors.stl]
2024-04-23 Revert "finalized"
    This reverts commit 2e05e6b4ecec5e69936743d7d32a3a3b6fd4fdf7.
    [source.ino]
